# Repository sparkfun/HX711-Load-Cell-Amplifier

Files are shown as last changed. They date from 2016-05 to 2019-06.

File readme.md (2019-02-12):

HX711 Load Cell Amplifier
=======

Amplifier Layout

*[SparkFun Load Cell Amplifier - HX711](https://www.sparkfun.com/products/13230)*

The SparkFun Load Cell Amplifier is a small breakout board for the HX711 IC that allows you to easily read load cells to measure weight. By connecting the amplifier to your microcontroller you will be able to read the changes in the resistance of the load cell and with some calibration you’ll be able to get very accurate weight measurements. This can be handy for creating your own industrial scale, process control, or simple presence detection of an object.

The HX711 uses a two wire interface (Clock and Data) for communication. Any microcontroller’s GPIO pins should work and numerous libraries have been written making it easy to read data from the HX711.

Load cells use a four wire wheatstone bridge to connect to the HX711. These are commonly colored RED, BLK, WHT, GRN, and YLW. Each color corresponds to the conventional color coding of load cells:

* Red (Excitation+ or VCC)
* Black (Excitation- or GND)
* White (Amplifier+, Signal+, or Output+)
* Green (A-, S-, or O-)
* Yellow (Shield)

The YLW pin acts as an optional input that is not hooked up to the strain gauge but is utilized to ground and shield against outside EMI (electromagnetic interference). Please keep in mind that some load cells might have slight variations in color coding.

Repository Contents
-------------------

* **/Production_Files** - Panelized version of the design for production
* **/datasheets** - Datasheet for HX711 IC
* **/firmware** - Example Arduino sketches
* **/hardware** - All Eagle design files (.brd, .sch)

Documentation
--------------
* **[Library](https://github.com/bogde/HX711)** - Arduino library for the HX711
* **[Getting Started with Load Cells](https://learn.sparkfun.com/tutorials/getting-started-with-load-cells)** - Introduction to Load Cells
* **[Hookup Guide](https://learn.sparkfun.com/tutorials/load-cell-amplifier-hx711-breakout-hookup-guide)** - Basic hookup guide for the Load Cell Amplifier

License Information
-------------------

This design is [OSHW](http://www.oshwa.org/definition/) and public domain but you buy me a beer if you use this and we meet someday ([Beerware license](http://en.wikipedia.org/wiki/Beerware)).

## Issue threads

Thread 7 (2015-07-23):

Analog/Digital VDD

robwyatt, 2015-07-23:
I originally posted this to tech support, but they suggested I post here too.

If you guys respin this breakout board could you separate analog and digital supplies. The hx711 has separate digital and analog supplies but your board ties them together so its a pain to use with 3.3v micro and 5v strain gauge. If you bring the digital supply to the header people can externally tie them together if they want 5v digital.

The digital pins have to be the same voltage as the DVDD pin so running on 5v wasn't ideal, level shifting it possible but not ideal, running the whole thing on 3.3v kind of works but with less voltage on the strain gauge its a lot more susceptible to errors.

Ultimately I cut the track to pin 16 (DVDD) to isolate digital supply pin and soldered a wire to it for 3.3v - works like a charm but its messy.
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

ToniCorinne, 2015-07-27:
Thank you for the feedback! We'll keep this feedback in mind if/when this product comes up for review.

jmaerki, 2016-01-01:
A jumper for easy switching RATE between GND and DVDD would also be nice for experiments.

nseidle, 2016-01-21:
@jmaerki - Thanks for the feedback. Do check the schematic and the back of the PCB. There is a jumper that allows you connect RATE to GND or VCC.

AlexeiUOA, 2016-02-16:
Hi robwyatt,
I have the same goal, to increase the voltage on the load cell excitation to 5V.
The data sheet for the HX711 states that when using internal analog supply regulator, "The output voltage is equal to VAVDD=VBG*(R1+T2)/R1" where VBG is the "Reference bypass output"
Using the resistor values from the break out board, I get 1.25*(20+8.2)/20=1.76V.
So will changing the supply voltage 3V to 5V effect the excitation voltage, without the need to change the resisters? Or is there something I am missing?
Thanks in advanced!

AlexeiUOA, 2016-02-17:
Hi robwyatt,
Some interesting reading regarding ADC's and why the AVGND and DVGND are tied. Basically treat ADC's as analog devices, even though internally they are mixed systems. Tying the grounds reduces the noise that gets coupled from the digital side to the analog side from stray/parasitic capacitance.
The article condemns connecting DVGND to your projects digital ground plane, as this will cause a noisy ground plane for the ADC! Consistently the interference from this may be greater then the 2X gain in sensitivity that is acquired by switching form a 3V to 5V excitation voltage for the strain bridge
[staying_well_grounded Analog Devices Grounding Guide.pdf](https://github.com/sparkfun/HX711-Load-Cell-Amplifier/files/133583/staying_well_grounded.Analog.Devices.Grounding.Guide.pdf)
.

nseidle, 2016-02-18:
Hmm. Good points. We could provide a jumper to isolate the GNDs as well.

AlexeiUOA, 2016-02-18:
Hi nseidle,
Could you please clarify how the excitation voltage is calculated?
Because from the data sheet of HX711, then there will be a constant 1.76V at the excitation, independent of the input voltage using VAVDD=VBG(R1+T2)/R1 (so long as the supply voltage is between 2.6V and 5.5V).
And if I was to modify the breakout board circuit by replacing R2 with a 52K resister, what type of resister would I need? ie foot print on the PCB.
Do you know what type of resisters technology is used for R1 and R2 currently? eg Metal oxide, thin film, Bulk metal foil? (Just thinking of the temperature coefficient)
Many thanks

tk5ep, 2016-03-16:
Hi all,
I came to this post, looking for some infos about the HX711.
I noticed some strange things...

On both boards i have (not the Sparkfun but similar), i measured 1.287 V on the VBG pin.
The R1 and R2 resistors are respectively 20k and 8.2k

So the given formula gives : 1.287V *(28200)/20000 = 1.81V

BUT on the cell i measured the VAVDD and found 4.10 V on both boards.

I tried reversing R1 and R2, the formula gives : 1.287V *( 28200 ) /8200 = 4.42 V
So, something is wrong somewhere !

Who else did measure the VAVDD voltage ?? What are the values ?

Another point, regarding the AVDD and DVDD voltages. The datasheet says that the common mode input is max AVDD-1.3.
Can someone tell me (us) what that means ?

Many thanks,
Patrick.

ba05, 2020-11-27:
Old post but the old data sheet I believe had a wrong formula for calculating the excitation. Correct is AVDD = VBG(R1+R2)/R2

See here https://cdn.sparkfun.com/assets/f/5/5/b/c/SparkFun_HX711_Load_Cell.pdf

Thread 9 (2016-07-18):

HX711 Standalone

Priya003, 2016-07-18:
Hi, wanted to use HX711 24-bit adc standalone to measure voltage range of 2mv - 20mv.
Problem is:
1) I cannot interpret the adc output count.
2) What should i do in my code(code below) so that it prints voltages not decimal values.
Tried with different values of voltages(shared below), and i am totally confused with the readings. I don't know how to convert these values in voltage. What is the logic behind. Please help!
Readings:
0mv --- 5219
1.1mv --- 5095
2.3mv --- 4981
2.5mv --- 4960
2.9mv --- 4918
5mv --- 4693
10.6mv --- 4075
15.1mv --- 3597
22.7mv --- 2700
40.7mv --- 562
5volts --- -8388608
-5volts --- -8388607
Board is arduino leonardo, and a simple voltage divider is used for voltage generation(for testing only). The voltages are measured and calculated from multimeter and hand calculations. I need HX711 do this for me. What is the differential ADC count and voltage relationship...?
A bogde/HX711 library is used: https://github.com/bogde/HX711
Code:
`#include "HX711.h"
#define DOUT 3
#define CLK 2
HX711 scale(DOUT, CLK);
void setup() {
Serial.begin(115200);
}
void loop() {
long avg = scale.get_value(60);
Serial.print("Digital Code = ");
Serial.println(avg);
}`
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

BrentWilkins, 2016-07-18:
[Here](https://learn.sparkfun.com/tutorials/load-cell-amplifier-hx711-breakout-hookup-guide) is our documentation on our HX711 Breakout. We don't necessarily support 3rd party code. If you have more questions, please try asking in our [forums]9https://forum.sparkfun.com/) or our tech support team.

robwyatt, 2016-07-18:
I would suggest the hx711 is not the correct part for what you are trying to do. At best case you are way out of spec because its going to expect A+ and A- to be very close and somewhere near the half way point of E+ and E-, its not going to expect one of them to be grounded even if the voltage between them is only 20mv. More complex load cell systems would go in to error more if you did this because they sense it as a short circuit. The Sparkfun board also uses the built in voltage regulator so E+ is not simply VCC, E+ is being driven by the PNP transistor, via the base and feedback pins on the hx711 and I haven't really looked at what that pin does and I can't even speculate what it does if you ground one of the inputs.

If you have a single ended input I would suggest one of the many ADCs out there that will measure 20mv, at worst case use an op amp to condition the input.

If you want to use this in an esoteric way then you really have to start with a resistor bridge, get valid readings and then manipulate the bridge and resistor values until you get something you can use and that makes sense.

Closed 2016-07-18.

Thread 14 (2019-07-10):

Calibration

GoncaloFelicio, 2019-07-10:
Hi!
I would like to know more about calibration. Is specific, does the setup influence the calibration factor, or is the calibration factor a number i get from the calibration sketch and then i always use that same calibration factor?

In my case, i want to setup 4 loadcells to the same wood board, but can i calibrate before i screw them to the board, or can i only calibrate after i have my setup?

Thanks!

santaimpersonator, 2019-07-12:
Hi there, it sounds like you are looking for [technical assistance](https://www.sparkfun.com/technical_assistance). Unfortunately, this is not the place to get technical support; it is for filing problems with the code, library, or hardware. Use the link (above), to get started with posting a topic in our [forums](https://forum.sparkfun.com/). Our technical support team will do their best to assist you.

That being said, please check out the guides associated with this product:

- [Load Cell Amplifier HX711 Breakout Hookup Guide](https://learn.sparkfun.com/tutorials/load-cell-amplifier-hx711-breakout-hookup-guide)
- [Getting Started with Load Cells](https://learn.sparkfun.com/tutorials/getting-started-with-load-cells)

Closed 2019-07-12.

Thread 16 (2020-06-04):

RATE pin tied to VCC instead of VDD

santaimpersonator, 2020-06-04:
Brought up by customer: https://www.sparkfun.com/products/13879#comment-5ed8c67e423fad306c45dec4

`RATE` pin is a digital input an should be tied to VDD.

santaimpersonator, 2020-10-08:
From issue #7: https://github.com/sparkfun/HX711-Load-Cell-Amplifier/issues/7#issuecomment-168311195

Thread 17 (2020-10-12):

Feature Request: Filter on Channel B

santaimpersonator, 2020-10-12:
One of our customers suggested that including the filter, currently, on channel A to channel B as well... would be useful for customers.

farzadVaziriRaieni, 2023-06-12:
Does anyone know the part number of the L1 component? Is it actually a coil or a ferrite bead?

santaimpersonator, 2023-06-12:
@farzadVaziriRaieni For tracking purposes and best practice... please, create a new issue and avoid commenting a question on an unrelated post. (I am hiding you comment for now, but I will delete it by the end of the day as it is unrelated to this issue.)

With that said...

- You can refer to the SparkFun Eagle library for that component:
  https://github.com/sparkfun/SparkFun-Eagle-Libraries/blob/main/SparkFun-Coils.lbr#L1607
- You can also refer to the image of the product as well:
  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

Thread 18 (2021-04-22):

Connecting to LabVIEW (Cant find i2c slave address)

YudiNz, 2021-04-22:
hi there, I am trying to hook this up to a LabVIEW myRio student board and am running into problems.

I can design it such that I do not need a slave address to communicate but currently am trying to find out what the HX711 boards slave address is. Could someone help direct me to where I can find it. Currently the information below is what I know about it:

Information sent is between 800000h (MIN) or 7FFFFFh (MAX) which translates to 24bits in binary or 3 bytes of data
Pulse clock 25 times to read data that has a adc gain of 128 or 27 Pulses for a gain of 64.

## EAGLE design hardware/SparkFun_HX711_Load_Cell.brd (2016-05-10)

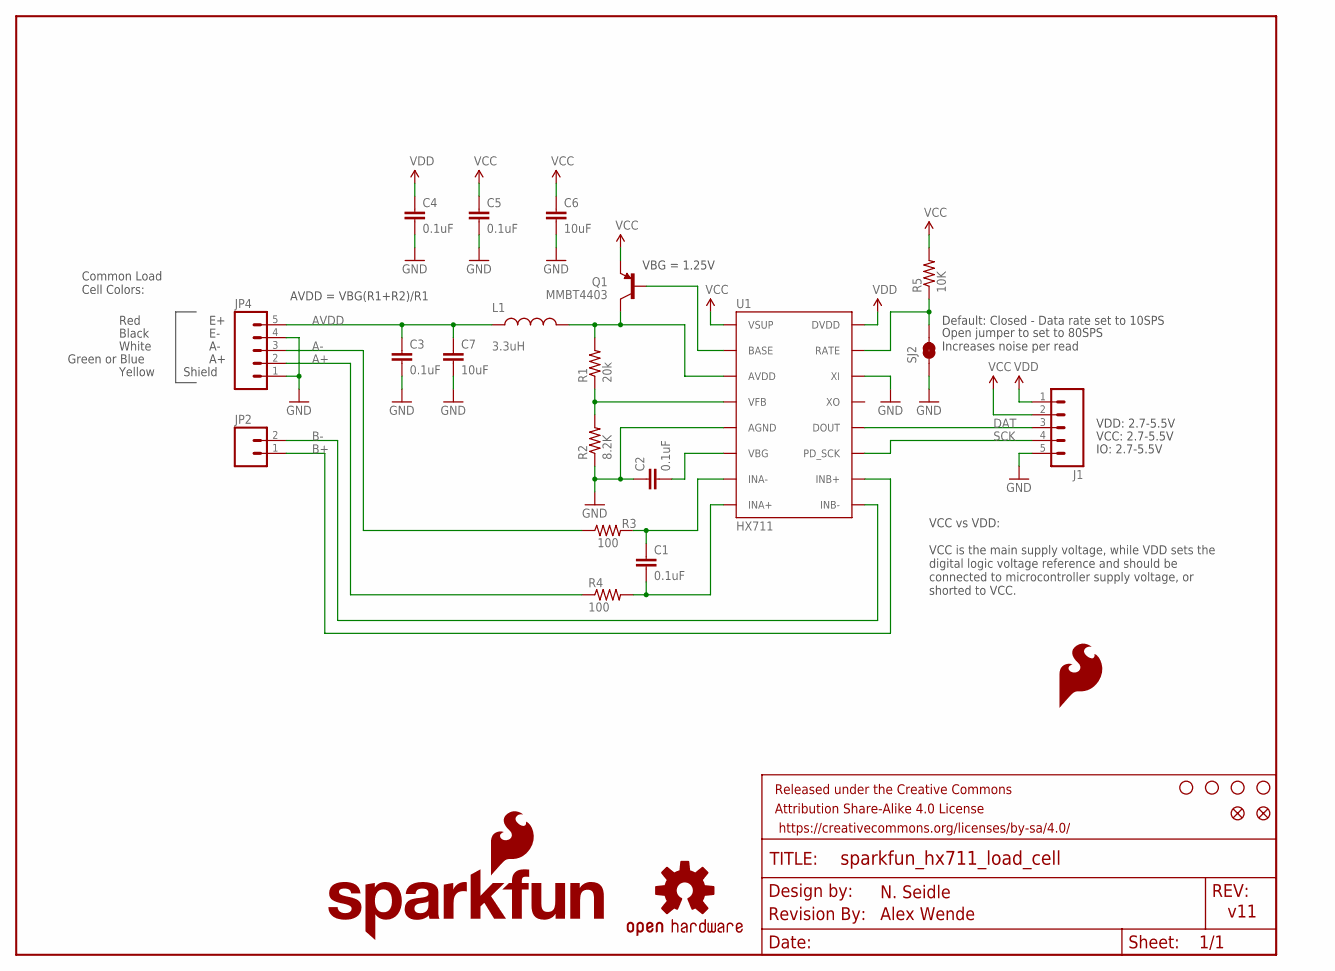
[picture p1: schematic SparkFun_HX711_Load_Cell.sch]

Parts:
C1, C2, C3, C4, C5: 0.1uF; 0603-CAP
C6, C7: 10uF; 1210
FID1, FID2: FIDUCIAL1X2; FIDUCIAL-1X2
FRAME1: FRAME-LETTER; CREATIVE_COMMONS
J1: M05PTH; 1X05
JP2: M02PTH; 1X02
JP4: M05PTH; 1X05
L1: 3.3uH; 0805
LOGO1: SFE_LOGO_NAME_FLAME.1_INCH; SFE_LOGO_NAME_FLAME_.1
LOGO3: SFE_LOGO_FLAME.1_INCH; SFE_LOGO_FLAME_.1
Q1: MMBT4403; SOT23-3
R1: 20k; 0603-RES
R2: 8.2K; 0603-RES
R3, R4: 100; 0603-RES
R5: 10K; 0603-RES
SJ2: JUMPER-PAD-2-NC_BY_TRACE; PAD-JUMPER-2-NC_BY_TRACE_YES_SILK
STANDOFF1, STANDOFF2, STANDOFF3, STANDOFF4: STAND-OFF
U1: HX711; SO16
U7: OSHW-LOGOS; OSHW-LOGO-S
U$1: REVISION

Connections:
A+: JP4.2, R4.1
A-: JP4.3, R3.1
AVDD: C3.1, C7.1, JP4.5, L1.1
B+: JP2.1, U1.10 (INB+)
B-: JP2.2, U1.9 (INB-)
DAT: J1.3, U1.12 (DOUT)
GND: C2.1, C3.2, C4.2, C5.2, C6.2, C7.2, J1.5, JP4.1, JP4.4, R2.1, SJ2.1, U1.5 (AGND), U1.14 (XI)
unnamed: R5.1, SJ2.2, U1.15 (RATE)
unnamed: C1.1, R3.2, U1.7 (INA-)
unnamed: C1.2, R4.2, U1.8 (INA+)
unnamed: Q1.1 (B), U1.2 (BASE)
unnamed: L1.2, Q1.3 (C), R1.2, U1.3 (AVDD)
unnamed: R1.1, R2.2, U1.4 (VFB)
unnamed: C2.2, U1.6 (VBG)
SCK: J1.4, U1.11 (PD_SCK)
VCC: C5.1, C6.1, J1.2, Q1.2 (E), R5.2, U1.1 (VSUP)
VDD: C4.1, J1.1, U1.16 (DVDD)

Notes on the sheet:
VCC: 2.7-5.5V
VBG = 1.25V
AVDD = VBG(R1+R2)/R1
Default: Closed - Data rate set to 10SPS
Open jumper to set to 80SPS Increases noise per read
Red
Black
White
Green or Blue
Common Load Cell Colors:
IO: 2.7-5.5V
Shield
Yellow
VDD: 2.7-5.5V
VCC vs VDD: VCC is the main supply voltage, while VDD sets the digital logic voltage reference and should be connected to microcontroller supply voltage, or shorted to VCC.
Alex Wende
N. Seidle
v11

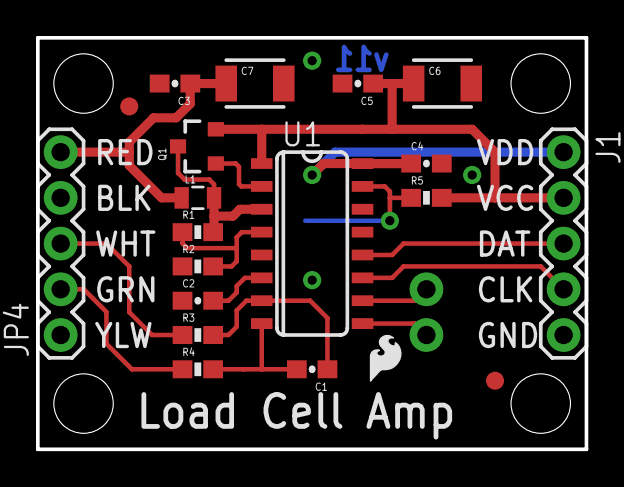
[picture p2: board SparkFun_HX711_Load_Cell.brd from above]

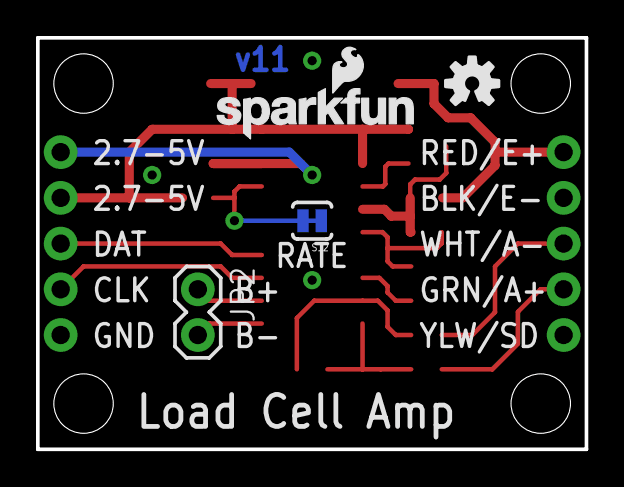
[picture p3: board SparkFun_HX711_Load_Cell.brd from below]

Board: 2 copper layers, 30.5 x 22.9 mm, 30 parts (4 on the bottom side), 17 nets.

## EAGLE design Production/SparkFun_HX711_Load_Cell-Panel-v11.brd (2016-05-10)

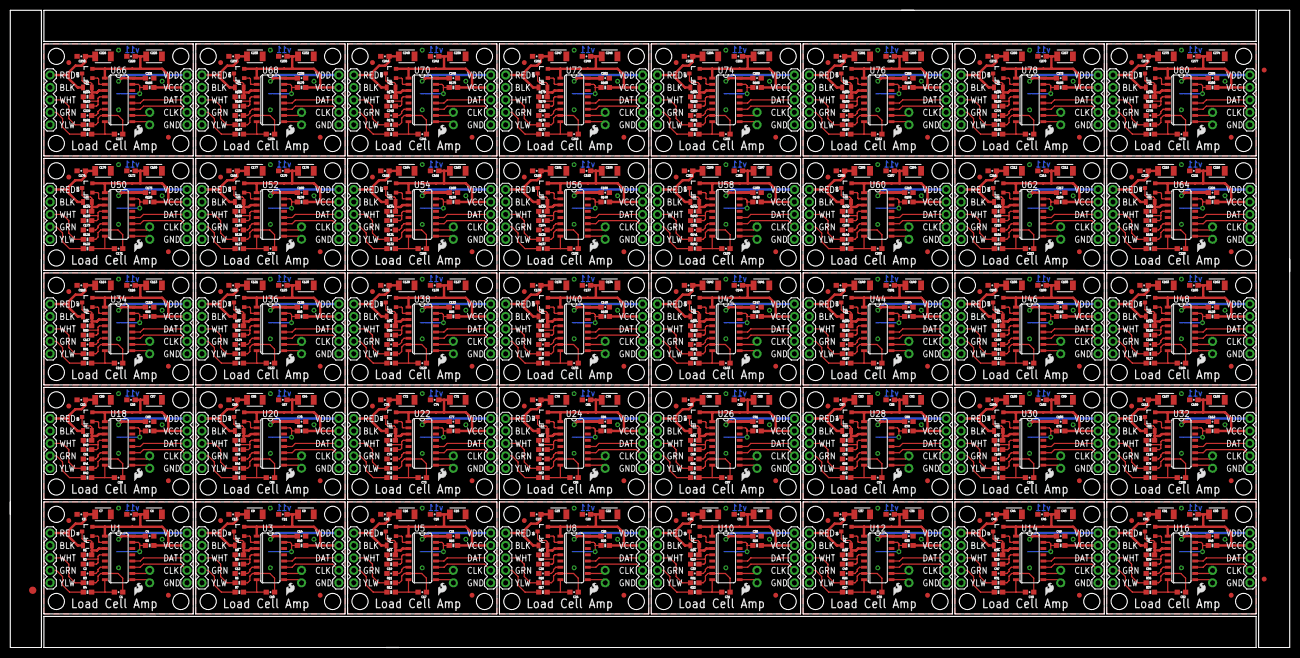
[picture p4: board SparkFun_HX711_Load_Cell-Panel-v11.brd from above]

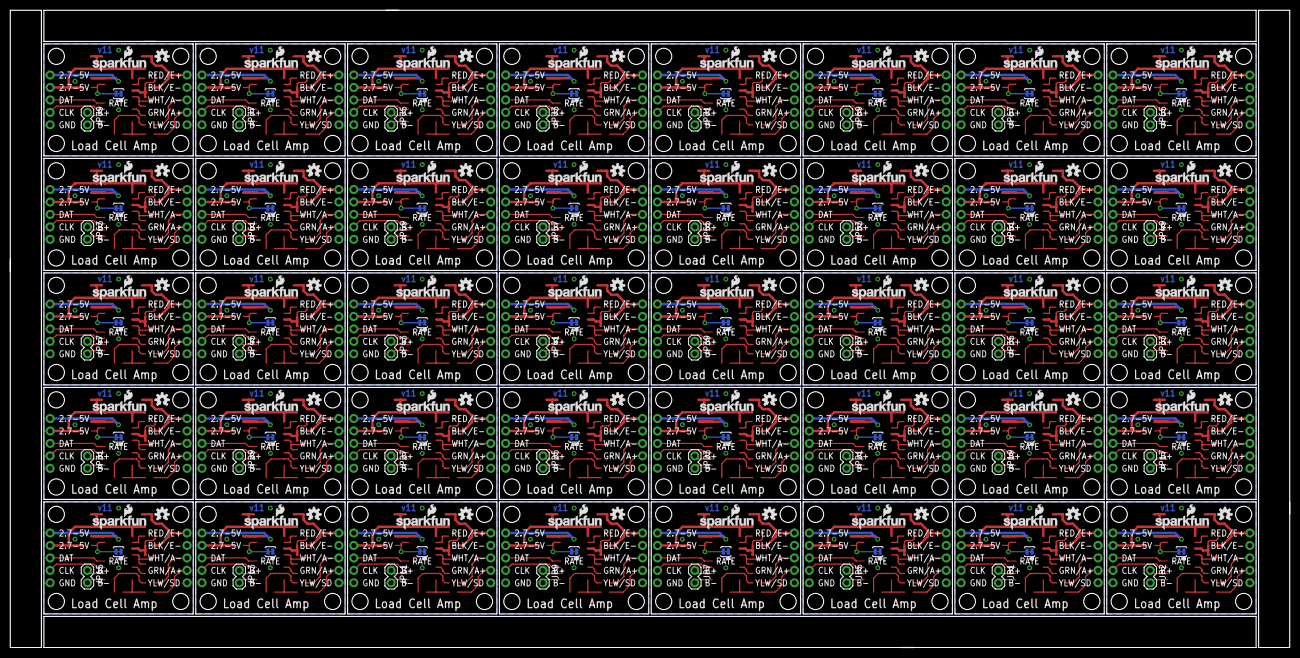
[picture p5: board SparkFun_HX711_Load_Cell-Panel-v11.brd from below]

Board: 2 copper layers, 261.1 x 130.0 mm, 1123 parts (160 on the bottom side), 680 nets.

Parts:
C1, C2, C3, C4, C5, C10, C11, C12, C13, C14, C17, C18, C19, C20, C21, C24, C25, C26, C27, C28, C31, C32, C33, C34, C35, C38, C39, C40, C41, C42, C45, C46, C47, C48, C49, C52, C53, C54, C55, C56, C59, C60, C61, C62, C63, C66, C67, C68, C69, C70, C73, C74, C75, C76, C77, C80, C81, C82, C83, C84, C87, C88, C89, C90, C91, C94, C95, C96, C97, C98, C101, C102, C103, C104, C105, C108, C109, C110, C111, C112, C115, C116, C117, C118, C119, C122, C123, C124, C125, C126, C129, C130, C131, C132, C133, C136, C137, C138, C139, C140, C143, C144, C145, C146, C147, C150, C151, C152, C153, C154, C157, C158, C159, C160, C161, C164, C165, C166, C167, C168, C171, C172, C173, C174, C175, C178, C179, C180, C181, C182, C185, C186, C187, C188, C189, C192, C193, C194, C195, C196, C199, C200, C201, C202, C203, C206, C207, C208, C209, C210, C213, C214, C215, C216, C217, C220, C221, C222, C223, C224, C227, C228, C229, C230, C231, C234, C235, C236, C237, C238, C241, C242, C243, C244, C245, C248, C249, C250, C251, C252, C255, C256, C257, C258, C259, C262, C263, C264, C265, C266, C269, C270, C271, C272, C273, C276, C277, C278, C279, C280: 0.1uF; 0603-CAP
C6, C7, C8, C9, C15, C16, C22, C23, C29, C30, C36, C37, C43, C44, C50, C51, C57, C58, C64, C65, C71, C72, C78, C79, C85, C86, C92, C93, C99, C100, C106, C107, C113, C114, C120, C121, C127, C128, C134, C135, C141, C142, C148, C149, C155, C156, C162, C163, C169, C170, C176, C177, C183, C184, C190, C191, C197, C198, C204, C205, C211, C212, C218, C219, C225, C226, C232, C233, C239, C240, C246, C247, C253, C254, C260, C261, C267, C268, C274, C275: 10uF; 1210
E$1: FIDUCIAL-1.5X3
E$5, E$6: FIDUCIAL-1X2
FID1, FID2, FID3, FID4, FID5, FID6, FID7, FID8, FID9, FID10, FID11, FID12, FID13, FID14, FID15, FID16, FID17, FID18, FID19, FID20, FID21, FID22, FID23, FID24, FID25, FID26, FID27, FID28, FID29, FID30, FID31, FID32, FID33, FID34, FID35, FID36, FID37, FID38, FID39, FID40, FID41, FID42, FID43, FID44, FID45, FID46, FID47, FID48, FID49, FID50, FID51, FID52, FID53, FID54, FID55, FID56, FID57, FID58, FID59, FID60, FID61, FID62, FID63, FID64, FID65, FID66, FID67, FID68, FID69, FID70, FID71, FID72, FID73, FID74, FID75, FID76, FID77, FID78, FID79, FID80: FIDUCIAL1X2; FIDUCIAL-1X2
J1, J2, J3, J4, J5, J6, J7, J8, J9, J10, J11, J12, J13, J14, J15, J16, J17, J18, J19, J20, J21, J22, J23, J24, J25, J26, J27, J28, J29, J30, J31, J32, J33, J34, J35, J36, J37, J38, J39, J40: 1X05
JP1, JP2, JP5, JP7, JP9, JP11, JP13, JP15, JP17, JP19, JP21, JP23, JP25, JP27, JP29, JP31, JP33, JP35, JP37, JP39, JP41, JP43, JP45, JP47, JP49, JP51, JP53, JP55, JP57, JP59, JP61, JP63, JP65, JP67, JP69, JP71, JP73, JP75, JP77, JP79: 1X02
JP3, JP4, JP6, JP8, JP10, JP12, JP14, JP16, JP18, JP20, JP22, JP24, JP26, JP28, JP30, JP32, JP34, JP36, JP38, JP40, JP42, JP44, JP46, JP48, JP50, JP52, JP54, JP56, JP58, JP60, JP62, JP64, JP66, JP68, JP70, JP72, JP74, JP76, JP78, JP80: 1X05
L1, L2, L3, L4, L5, L6, L7, L8, L9, L10, L11, L12, L13, L14, L15, L16, L17, L18, L19, L20, L21, L22, L23, L24, L25, L26, L27, L28, L29, L30, L31, L32, L33, L34, L35, L36, L37, L38, L39, L40: 3.3uH; 0805
LOGO1, LOGO2, LOGO5, LOGO7, LOGO9, LOGO11, LOGO13, LOGO15, LOGO17, LOGO19, LOGO21, LOGO23, LOGO25, LOGO27, LOGO29, LOGO31, LOGO33, LOGO35, LOGO37, LOGO39, LOGO41, LOGO43, LOGO45, LOGO47, LOGO49, LOGO51, LOGO53, LOGO55, LOGO57, LOGO59, LOGO61, LOGO63, LOGO65, LOGO67, LOGO69, LOGO71, LOGO73, LOGO75, LOGO77, LOGO79: SFE_LOGO_NAME_FLAME.1_INCH; SFE_LOGO_NAME_FLAME_.1
LOGO3, LOGO4, LOGO6, LOGO8, LOGO10, LOGO12, LOGO14, LOGO16, LOGO18, LOGO20, LOGO22, LOGO24, LOGO26, LOGO28, LOGO30, LOGO32, LOGO34, LOGO36, LOGO38, LOGO40, LOGO42, LOGO44, LOGO46, LOGO48, LOGO50, LOGO52, LOGO54, LOGO56, LOGO58, LOGO60, LOGO62, LOGO64, LOGO66, LOGO68, LOGO70, LOGO72, LOGO74, LOGO76, LOGO78, LOGO80: SFE_LOGO_FLAME.1_INCH; SFE_LOGO_FLAME_.1
Q1, Q2, Q3, Q4, Q5, Q6, Q7, Q8, Q9, Q10, Q11, Q12, Q13, Q14, Q15, Q16, Q17, Q18, Q19, Q20, Q21, Q22, Q23, Q24, Q25, Q26, Q27, Q28, Q29, Q30, Q31, Q32, Q33, Q34, Q35, Q36, Q37, Q38, Q39, Q40: MMBT4403; SOT23-3
R1, R9, R14, R19, R24, R29, R34, R39, R44, R49, R54, R59, R64, R69, R74, R79, R84, R89, R94, R99, R104, R109, R114, R119, R124, R129, R134, R139, R144, R149, R154, R159, R164, R169, R174, R179, R184, R189, R194, R199: 20k; 0603-RES
R2, R8, R13, R18, R23, R28, R33, R38, R43, R48, R53, R58, R63, R68, R73, R78, R83, R88, R93, R98, R103, R108, R113, R118, R123, R128, R133, R138, R143, R148, R153, R158, R163, R168, R173, R178, R183, R188, R193, R198: 8.2K; 0603-RES
R3, R4, R6, R7, R11, R12, R16, R17, R21, R22, R26, R27, R31, R32, R36, R37, R41, R42, R46, R47, R51, R52, R56, R57, R61, R62, R66, R67, R71, R72, R76, R77, R81, R82, R86, R87, R91, R92, R96, R97, R101, R102, R106, R107, R111, R112, R116, R117, R121, R122, R126, R127, R131, R132, R136, R137, R141, R142, R146, R147, R151, R152, R156, R157, R161, R162, R166, R167, R171, R172, R176, R177, R181, R182, R186, R187, R191, R192, R196, R197: 100; 0603-RES
R5, R10, R15, R20, R25, R30, R35, R40, R45, R50, R55, R60, R65, R70, R75, R80, R85, R90, R95, R100, R105, R110, R115, R120, R125, R130, R135, R140, R145, R150, R155, R160, R165, R170, R175, R180, R185, R190, R195, R200: 10K; 0603-RES
SJ1, SJ2, SJ3, SJ4, SJ5, SJ6, SJ7, SJ8, SJ9, SJ10, SJ11, SJ12, SJ13, SJ14, SJ15, SJ16, SJ17, SJ18, SJ19, SJ20, SJ21, SJ22, SJ23, SJ24, SJ25, SJ26, SJ27, SJ28, SJ29, SJ30, SJ31, SJ32, SJ33, SJ34, SJ35, SJ36, SJ37, SJ38, SJ39, SJ40: PAD-JUMPER-2-NC_BY_TRACE_YES_SILK
STANDOFF1, STANDOFF2, STANDOFF3, STANDOFF4, STANDOFF5, STANDOFF6, STANDOFF7, STANDOFF8, STANDOFF9, STANDOFF10, STANDOFF11, STANDOFF12, STANDOFF13, STANDOFF14, STANDOFF15, STANDOFF16, STANDOFF17, STANDOFF18, STANDOFF19, STANDOFF20, STANDOFF21, STANDOFF22, STANDOFF23, STANDOFF24, STANDOFF25, STANDOFF26, STANDOFF27, STANDOFF28, STANDOFF29, STANDOFF30, STANDOFF31, STANDOFF32, STANDOFF33, STANDOFF34, STANDOFF35, STANDOFF36, STANDOFF37, STANDOFF38, STANDOFF39, STANDOFF40, STANDOFF41, STANDOFF42, STANDOFF43, STANDOFF44, STANDOFF45, STANDOFF46, STANDOFF47, STANDOFF48, STANDOFF49, STANDOFF50, STANDOFF51, STANDOFF52, STANDOFF53, STANDOFF54, STANDOFF55, STANDOFF56, STANDOFF57, STANDOFF58, STANDOFF59, STANDOFF60, STANDOFF61, STANDOFF62, STANDOFF63, STANDOFF64, STANDOFF65, STANDOFF66, STANDOFF67, STANDOFF68, STANDOFF69, STANDOFF70, STANDOFF71, STANDOFF72, STANDOFF73, STANDOFF74, STANDOFF75, STANDOFF76, STANDOFF77, STANDOFF78, STANDOFF79, STANDOFF80, STANDOFF81, STANDOFF82, STANDOFF83, STANDOFF84, STANDOFF85, STANDOFF86, STANDOFF87, STANDOFF88, STANDOFF89, STANDOFF90, STANDOFF91, STANDOFF92, STANDOFF93, STANDOFF94, STANDOFF95, STANDOFF96, STANDOFF97, STANDOFF98, STANDOFF99, STANDOFF100, STANDOFF101, STANDOFF102, STANDOFF103, STANDOFF104, STANDOFF105, STANDOFF106, STANDOFF107, STANDOFF108, STANDOFF109, STANDOFF110, STANDOFF111, STANDOFF112, STANDOFF113, STANDOFF114, STANDOFF115, STANDOFF116, STANDOFF117, STANDOFF118, STANDOFF119, STANDOFF120, STANDOFF121, STANDOFF122, STANDOFF123, STANDOFF124, STANDOFF125, STANDOFF126, STANDOFF127, STANDOFF128, STANDOFF129, STANDOFF130, STANDOFF131, STANDOFF132, STANDOFF133, STANDOFF134, STANDOFF135, STANDOFF136, STANDOFF137, STANDOFF138, STANDOFF139, STANDOFF140, STANDOFF141, STANDOFF142, STANDOFF143, STANDOFF144, STANDOFF145, STANDOFF146, STANDOFF147, STANDOFF148, STANDOFF149, STANDOFF150, STANDOFF151, STANDOFF152, STANDOFF153, STANDOFF154, STANDOFF155, STANDOFF156, STANDOFF157, STANDOFF158, STANDOFF159, STANDOFF160: STAND-OFF
U1, U3, U5, U8, U10, U12, U14, U16, U18, U20, U22, U24, U26, U28, U30, U32, U34, U36, U38, U40, U42, U44, U46, U48, U50, U52, U54, U56, U58, U60, U62, U64, U66, U68, U70, U72, U74, U76, U78, U80: HX711; SO16
U2, U4, U6, U7, U9, U11, U13, U15, U17, U19, U21, U23, U25, U27, U29, U31, U33, U35, U37, U39, U41, U43, U45, U47, U49, U51, U53, U55, U57, U59, U61, U63, U65, U67, U69, U71, U73, U75, U77, U79: OSHW-LOGOS; OSHW-LOGO-S

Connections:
A+: JP4.2, R4.1
A+1: JP3.2, R7.1
A+2: JP6.2, R12.1
A+3: JP8.2, R17.1
A+4: JP10.2, R22.1
A+5: JP12.2, R27.1
A+6: JP14.2, R32.1
A+7: JP16.2, R37.1
A+8: JP18.2, R42.1
A+9: JP20.2, R47.1
A+10: JP22.2, R52.1
A+11: JP24.2, R57.1
A+12: JP26.2, R62.1
A+13: JP28.2, R67.1
A+14: JP30.2, R72.1
A+15: JP32.2, R77.1
A+16: JP34.2, R82.1
A+17: JP36.2, R87.1
A+18: JP38.2, R92.1
A+19: JP40.2, R97.1
A+20: JP42.2, R102.1
A+21: JP44.2, R107.1
A+22: JP46.2, R112.1
A+23: JP48.2, R117.1
A+24: JP50.2, R122.1
A+25: JP52.2, R127.1
A+26: JP54.2, R132.1
A+27: JP56.2, R137.1
A+28: JP58.2, R142.1
A+29: JP60.2, R147.1
A+30: JP62.2, R152.1
A+31: JP64.2, R157.1
A+32: JP66.2, R162.1
A+33: JP68.2, R167.1
A+34: JP70.2, R172.1
A+35: JP72.2, R177.1
A+36: JP74.2, R182.1
A+37: JP76.2, R187.1
A+38: JP78.2, R192.1
A+39: JP80.2, R197.1
A-: JP4.3, R3.1
A-1: JP3.3, R6.1
A-2: JP6.3, R11.1
A-3: JP8.3, R16.1
A-4: JP10.3, R21.1
A-5: JP12.3, R26.1
A-6: JP14.3, R31.1
A-7: JP16.3, R36.1
A-8: JP18.3, R41.1
A-9: JP20.3, R46.1
A-10: JP22.3, R51.1
A-11: JP24.3, R56.1
A-12: JP26.3, R61.1
A-13: JP28.3, R66.1
A-14: JP30.3, R71.1
A-15: JP32.3, R76.1
A-16: JP34.3, R81.1
A-17: JP36.3, R86.1
A-18: JP38.3, R91.1
A-19: JP40.3, R96.1
A-20: JP42.3, R101.1
A-21: JP44.3, R106.1
A-22: JP46.3, R111.1
A-23: JP48.3, R116.1
A-24: JP50.3, R121.1
A-25: JP52.3, R126.1
A-26: JP54.3, R131.1
A-27: JP56.3, R136.1
A-28: JP58.3, R141.1
A-29: JP60.3, R146.1
A-30: JP62.3, R151.1
A-31: JP64.3, R156.1
A-32: JP66.3, R161.1
A-33: JP68.3, R166.1
A-34: JP70.3, R171.1
A-35: JP72.3, R176.1
A-36: JP74.3, R181.1
A-37: JP76.3, R186.1
A-38: JP78.3, R191.1
A-39: JP80.3, R196.1
AVDD: C3.1, C7.1, JP4.5, L1.1
AVDD1: C9.1, C13.1, JP3.5, L2.1
AVDD2: C16.1, C20.1, JP6.5, L3.1
AVDD3: C23.1, C27.1, JP8.5, L4.1
AVDD4: C30.1, C34.1, JP10.5, L5.1
AVDD5: C37.1, C41.1, JP12.5, L6.1
AVDD6: C44.1, C48.1, JP14.5, L7.1
AVDD7: C51.1, C55.1, JP16.5, L8.1
AVDD8: C58.1, C62.1, JP18.5, L9.1
AVDD9: C65.1, C69.1, JP20.5, L10.1
AVDD10: C72.1, C76.1, JP22.5, L11.1
AVDD11: C79.1, C83.1, JP24.5, L12.1
AVDD12: C86.1, C90.1, JP26.5, L13.1
AVDD13: C93.1, C97.1, JP28.5, L14.1
AVDD14: C100.1, C104.1, JP30.5, L15.1
AVDD15: C107.1, C111.1, JP32.5, L16.1
AVDD16: C114.1, C118.1, JP34.5, L17.1
AVDD17: C121.1, C125.1, JP36.5, L18.1
AVDD18: C128.1, C132.1, JP38.5, L19.1
AVDD19: C135.1, C139.1, JP40.5, L20.1
AVDD20: C142.1, C146.1, JP42.5, L21.1
AVDD21: C149.1, C153.1, JP44.5, L22.1
AVDD22: C156.1, C160.1, JP46.5, L23.1
AVDD23: C163.1, C167.1, JP48.5, L24.1
AVDD24: C170.1, C174.1, JP50.5, L25.1
AVDD25: C177.1, C181.1, JP52.5, L26.1
AVDD26: C184.1, C188.1, JP54.5, L27.1
AVDD27: C191.1, C195.1, JP56.5, L28.1
AVDD28: C198.1, C202.1, JP58.5, L29.1
AVDD29: C205.1, C209.1, JP60.5, L30.1
AVDD30: C212.1, C216.1, JP62.5, L31.1
AVDD31: C219.1, C223.1, JP64.5, L32.1
AVDD32: C226.1, C230.1, JP66.5, L33.1
AVDD33: C233.1, C237.1, JP68.5, L34.1
AVDD34: C240.1, C244.1, JP70.5, L35.1
AVDD35: C247.1, C251.1, JP72.5, L36.1
AVDD36: C254.1, C258.1, JP74.5, L37.1
AVDD37: C261.1, C265.1, JP76.5, L38.1
AVDD38: C268.1, C272.1, JP78.5, L39.1
AVDD39: C275.1, C279.1, JP80.5, L40.1
B+: JP2.1, U1.10
B+1: JP1.1, U3.10
B+2: JP5.1, U5.10
B+3: JP7.1, U8.10
B+4: JP9.1, U10.10
B+5: JP11.1, U12.10
B+6: JP13.1, U14.10
B+7: JP15.1, U16.10
B+8: JP17.1, U18.10
B+9: JP19.1, U20.10
B+10: JP21.1, U22.10
B+11: JP23.1, U24.10
B+12: JP25.1, U26.10
B+13: JP27.1, U28.10
B+14: JP29.1, U30.10
B+15: JP31.1, U32.10
B+16: JP33.1, U34.10
B+17: JP35.1, U36.10
B+18: JP37.1, U38.10
B+19: JP39.1, U40.10
B+20: JP41.1, U42.10
B+21: JP43.1, U44.10
B+22: JP45.1, U46.10
B+23: JP47.1, U48.10
B+24: JP49.1, U50.10
B+25: JP51.1, U52.10
B+26: JP53.1, U54.10
B+27: JP55.1, U56.10
B+28: JP57.1, U58.10
B+29: JP59.1, U60.10
B+30: JP61.1, U62.10
B+31: JP63.1, U64.10
B+32: JP65.1, U66.10
B+33: JP67.1, U68.10
B+34: JP69.1, U70.10
B+35: JP71.1, U72.10
B+36: JP73.1, U74.10
B+37: JP75.1, U76.10
B+38: JP77.1, U78.10
B+39: JP79.1, U80.10
B-: JP2.2, U1.9
B-1: JP1.2, U3.9
B-2: JP5.2, U5.9
B-3: JP7.2, U8.9
B-4: JP9.2, U10.9
B-5: JP11.2, U12.9
B-6: JP13.2, U14.9
B-7: JP15.2, U16.9
B-8: JP17.2, U18.9
B-9: JP19.2, U20.9
B-10: JP21.2, U22.9
B-11: JP23.2, U24.9
B-12: JP25.2, U26.9
B-13: JP27.2, U28.9
B-14: JP29.2, U30.9
B-15: JP31.2, U32.9
B-16: JP33.2, U34.9
B-17: JP35.2, U36.9
B-18: JP37.2, U38.9
B-19: JP39.2, U40.9
B-20: JP41.2, U42.9
B-21: JP43.2, U44.9
B-22: JP45.2, U46.9
B-23: JP47.2, U48.9
B-24: JP49.2, U50.9
B-25: JP51.2, U52.9
B-26: JP53.2, U54.9
B-27: JP55.2, U56.9
B-28: JP57.2, U58.9
B-29: JP59.2, U60.9
B-30: JP61.2, U62.9
B-31: JP63.2, U64.9
B-32: JP65.2, U66.9
B-33: JP67.2, U68.9
B-34: JP69.2, U70.9
B-35: JP71.2, U72.9
B-36: JP73.2, U74.9
B-37: JP75.2, U76.9
B-38: JP77.2, U78.9
B-39: JP79.2, U80.9
DAT: J1.3, U1.12
DAT1: J2.3, U3.12
DAT2: J3.3, U5.12
DAT3: J4.3, U8.12
DAT4: J5.3, U10.12
DAT5: J6.3, U12.12
DAT6: J7.3, U14.12
DAT7: J8.3, U16.12
DAT8: J9.3, U18.12
DAT9: J10.3, U20.12
DAT10: J11.3, U22.12
DAT11: J12.3, U24.12
DAT12: J13.3, U26.12
DAT13: J14.3, U28.12
DAT14: J15.3, U30.12
DAT15: J16.3, U32.12
DAT16: J17.3, U34.12
DAT17: J18.3, U36.12
DAT18: J19.3, U38.12
DAT19: J20.3, U40.12
DAT20: J21.3, U42.12
DAT21: J22.3, U44.12
DAT22: J23.3, U46.12
DAT23: J24.3, U48.12
DAT24: J25.3, U50.12
DAT25: J26.3, U52.12
DAT26: J27.3, U54.12
DAT27: J28.3, U56.12
DAT28: J29.3, U58.12
DAT29: J30.3, U60.12
DAT30: J31.3, U62.12
DAT31: J32.3, U64.12
DAT32: J33.3, U66.12
DAT33: J34.3, U68.12
DAT34: J35.3, U70.12
DAT35: J36.3, U72.12
DAT36: J37.3, U74.12
DAT37: J38.3, U76.12
DAT38: J39.3, U78.12
DAT39: J40.3, U80.12
GND: C2.1, C3.2, C4.2, C5.2, C6.2, C7.2, J1.5, JP4.1, JP4.4, R2.1, SJ2.1, U1.5, U1.14
GND1: C8.2, C9.2, C11.2, C12.1, C13.2, C14.2, J2.5, JP3.1, JP3.4, R8.1, SJ1.1, U3.5, U3.14
GND2: C15.2, C16.2, C18.2, C19.1, C20.2, C21.2, J3.5, JP6.1, JP6.4, R13.1, SJ3.1, U5.5, U5.14
GND3: C22.2, C23.2, C25.2, C26.1, C27.2, C28.2, J4.5, JP8.1, JP8.4, R18.1, SJ4.1, U8.5, U8.14
GND4: C29.2, C30.2, C32.2, C33.1, C34.2, C35.2, J5.5, JP10.1, JP10.4, R23.1, SJ5.1, U10.5, U10.14
GND5: C36.2, C37.2, C39.2, C40.1, C41.2, C42.2, J6.5, JP12.1, JP12.4, R28.1, SJ6.1, U12.5, U12.14
GND6: C43.2, C44.2, C46.2, C47.1, C48.2, C49.2, J7.5, JP14.1, JP14.4, R33.1, SJ7.1, U14.5, U14.14
GND7: C50.2, C51.2, C53.2, C54.1, C55.2, C56.2, J8.5, JP16.1, JP16.4, R38.1, SJ8.1, U16.5, U16.14
GND8: C57.2, C58.2, C60.2, C61.1, C62.2, C63.2, J9.5, JP18.1, JP18.4, R43.1, SJ9.1, U18.5, U18.14
GND9: C64.2, C65.2, C67.2, C68.1, C69.2, C70.2, J10.5, JP20.1, JP20.4, R48.1, SJ10.1, U20.5, U20.14
GND10: C71.2, C72.2, C74.2, C75.1, C76.2, C77.2, J11.5, JP22.1, JP22.4, R53.1, SJ11.1, U22.5, U22.14
GND11: C78.2, C79.2, C81.2, C82.1, C83.2, C84.2, J12.5, JP24.1, JP24.4, R58.1, SJ12.1, U24.5, U24.14
GND12: C85.2, C86.2, C88.2, C89.1, C90.2, C91.2, J13.5, JP26.1, JP26.4, R63.1, SJ13.1, U26.5, U26.14
GND13: C92.2, C93.2, C95.2, C96.1, C97.2, C98.2, J14.5, JP28.1, JP28.4, R68.1, SJ14.1, U28.5, U28.14
GND14: C99.2, C100.2, C102.2, C103.1, C104.2, C105.2, J15.5, JP30.1, JP30.4, R73.1, SJ15.1, U30.5, U30.14
GND15: C106.2, C107.2, C109.2, C110.1, C111.2, C112.2, J16.5, JP32.1, JP32.4, R78.1, SJ16.1, U32.5, U32.14
GND16: C113.2, C114.2, C116.2, C117.1, C118.2, C119.2, J17.5, JP34.1, JP34.4, R83.1, SJ17.1, U34.5, U34.14
GND17: C120.2, C121.2, C123.2, C124.1, C125.2, C126.2, J18.5, JP36.1, JP36.4, R88.1, SJ18.1, U36.5, U36.14
GND18: C127.2, C128.2, C130.2, C131.1, C132.2, C133.2, J19.5, JP38.1, JP38.4, R93.1, SJ19.1, U38.5, U38.14
GND19: C134.2, C135.2, C137.2, C138.1, C139.2, C140.2, J20.5, JP40.1, JP40.4, R98.1, SJ20.1, U40.5, U40.14
GND20: C141.2, C142.2, C144.2, C145.1, C146.2, C147.2, J21.5, JP42.1, JP42.4, R103.1, SJ21.1, U42.5, U42.14
GND21: C148.2, C149.2, C151.2, C152.1, C153.2, C154.2, J22.5, JP44.1, JP44.4, R108.1, SJ22.1, U44.5, U44.14
GND22: C155.2, C156.2, C158.2, C159.1, C160.2, C161.2, J23.5, JP46.1, JP46.4, R113.1, SJ23.1, U46.5, U46.14
GND23: C162.2, C163.2, C165.2, C166.1, C167.2, C168.2, J24.5, JP48.1, JP48.4, R118.1, SJ24.1, U48.5, U48.14
GND24: C169.2, C170.2, C172.2, C173.1, C174.2, C175.2, J25.5, JP50.1, JP50.4, R123.1, SJ25.1, U50.5, U50.14
GND25: C176.2, C177.2, C179.2, C180.1, C181.2, C182.2, J26.5, JP52.1, JP52.4, R128.1, SJ26.1, U52.5, U52.14
GND26: C183.2, C184.2, C186.2, C187.1, C188.2, C189.2, J27.5, JP54.1, JP54.4, R133.1, SJ27.1, U54.5, U54.14
GND27: C190.2, C191.2, C193.2, C194.1, C195.2, C196.2, J28.5, JP56.1, JP56.4, R138.1, SJ28.1, U56.5, U56.14
GND28: C197.2, C198.2, C200.2, C201.1, C202.2, C203.2, J29.5, JP58.1, JP58.4, R143.1, SJ29.1, U58.5, U58.14
GND29: C204.2, C205.2, C207.2, C208.1, C209.2, C210.2, J30.5, JP60.1, JP60.4, R148.1, SJ30.1, U60.5, U60.14
GND30: C211.2, C212.2, C214.2, C215.1, C216.2, C217.2, J31.5, JP62.1, JP62.4, R153.1, SJ31.1, U62.5, U62.14
GND31: C218.2, C219.2, C221.2, C222.1, C223.2, C224.2, J32.5, JP64.1, JP64.4, R158.1, SJ32.1, U64.5, U64.14
GND32: C225.2, C226.2, C228.2, C229.1, C230.2, C231.2, J33.5, JP66.1, JP66.4, R163.1, SJ33.1, U66.5, U66.14
GND33: C232.2, C233.2, C235.2, C236.1, C237.2, C238.2, J34.5, JP68.1, JP68.4, R168.1, SJ34.1, U68.5, U68.14
GND34: C239.2, C240.2, C242.2, C243.1, C244.2, C245.2, J35.5, JP70.1, JP70.4, R173.1, SJ35.1, U70.5, U70.14
GND35: C246.2, C247.2, C249.2, C250.1, C251.2, C252.2, J36.5, JP72.1, JP72.4, R178.1, SJ36.1, U72.5, U72.14
GND36: C253.2, C254.2, C256.2, C257.1, C258.2, C259.2, J37.5, JP74.1, JP74.4, R183.1, SJ37.1, U74.5, U74.14
GND37: C260.2, C261.2, C263.2, C264.1, C265.2, C266.2, J38.5, JP76.1, JP76.4, R188.1, SJ38.1, U76.5, U76.14
GND38: C267.2, C268.2, C270.2, C271.1, C272.2, C273.2, J39.5, JP78.1, JP78.4, R193.1, SJ39.1, U78.5, U78.14
GND39: C274.2, C275.2, C277.2, C278.1, C279.2, C280.2, J40.5, JP80.1, JP80.4, R198.1, SJ40.1, U80.5, U80.14
unnamed: R5.1, SJ2.2, U1.15
unnamed: C1.1, R3.2, U1.7
unnamed: C1.2, R4.2, U1.8
unnamed: Q1.1, U1.2
unnamed: L1.2, Q1.3, R1.2, U1.3
unnamed: R1.1, R2.2, U1.4
unnamed: C2.2, U1.6
unnamed: Q2.1, U3.2
unnamed: R8.2, R9.1, U3.4
unnamed: C12.2, U3.6
unnamed: L2.2, Q2.3, R9.2, U3.3
unnamed: R10.1, SJ1.2, U3.15
unnamed: C10.1, R6.2, U3.7
unnamed: C10.2, R7.2, U3.8
unnamed: Q3.1, U5.2
unnamed: R13.2, R14.1, U5.4
unnamed: C19.2, U5.6
unnamed: L3.2, Q3.3, R14.2, U5.3
unnamed: R15.1, SJ3.2, U5.15
unnamed: C17.1, R11.2, U5.7
unnamed: C17.2, R12.2, U5.8
unnamed: Q4.1, U8.2
unnamed: R18.2, R19.1, U8.4
unnamed: C26.2, U8.6
unnamed: L4.2, Q4.3, R19.2, U8.3
unnamed: R20.1, SJ4.2, U8.15
unnamed: C24.1, R16.2, U8.7
unnamed: C24.2, R17.2, U8.8
unnamed: Q5.1, U10.2
unnamed: R23.2, R24.1, U10.4
unnamed: C33.2, U10.6
unnamed: L5.2, Q5.3, R24.2, U10.3
unnamed: R25.1, SJ5.2, U10.15
unnamed: C31.1, R21.2, U10.7
unnamed: C31.2, R22.2, U10.8
unnamed: Q6.1, U12.2
unnamed: R28.2, R29.1, U12.4
unnamed: C40.2, U12.6
unnamed: L6.2, Q6.3, R29.2, U12.3
unnamed: R30.1, SJ6.2, U12.15
unnamed: C38.1, R26.2, U12.7
unnamed: C38.2, R27.2, U12.8
unnamed: Q7.1, U14.2
unnamed: R33.2, R34.1, U14.4
unnamed: C47.2, U14.6
unnamed: L7.2, Q7.3, R34.2, U14.3
unnamed: R35.1, SJ7.2, U14.15
unnamed: C45.1, R31.2, U14.7
unnamed: C45.2, R32.2, U14.8
unnamed: Q8.1, U16.2
unnamed: R38.2, R39.1, U16.4
unnamed: C54.2, U16.6
unnamed: L8.2, Q8.3, R39.2, U16.3
unnamed: R40.1, SJ8.2, U16.15
unnamed: C52.1, R36.2, U16.7
unnamed: C52.2, R37.2, U16.8
unnamed: Q9.1, U18.2
unnamed: R43.2, R44.1, U18.4
unnamed: C61.2, U18.6
unnamed: L9.2, Q9.3, R44.2, U18.3
unnamed: R45.1, SJ9.2, U18.15
unnamed: C59.1, R41.2, U18.7
unnamed: C59.2, R42.2, U18.8
unnamed: Q10.1, U20.2
unnamed: R48.2, R49.1, U20.4
unnamed: C68.2, U20.6
unnamed: L10.2, Q10.3, R49.2, U20.3
unnamed: R50.1, SJ10.2, U20.15
unnamed: C66.1, R46.2, U20.7
unnamed: C66.2, R47.2, U20.8
unnamed: Q11.1, U22.2
unnamed: R53.2, R54.1, U22.4
unnamed: C75.2, U22.6
unnamed: L11.2, Q11.3, R54.2, U22.3
unnamed: R55.1, SJ11.2, U22.15
unnamed: C73.1, R51.2, U22.7
unnamed: C73.2, R52.2, U22.8
unnamed: Q12.1, U24.2
unnamed: R58.2, R59.1, U24.4
unnamed: C82.2, U24.6
unnamed: L12.2, Q12.3, R59.2, U24.3
unnamed: R60.1, SJ12.2, U24.15
unnamed: C80.1, R56.2, U24.7
unnamed: C80.2, R57.2, U24.8
unnamed: Q13.1, U26.2
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

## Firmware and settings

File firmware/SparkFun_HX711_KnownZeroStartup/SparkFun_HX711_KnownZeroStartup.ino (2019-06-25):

/*
 Example using the SparkFun HX711 breakout board with a scale
 By: Nathan Seidle
 SparkFun Electronics
 Date: November 19th, 2014
 License: This code is public domain but you buy me a beer if you use this and we meet someday (Beerware license).
 
 Most scales require that there be no weight on the scale during power on. This sketch shows how to pre-load tare values
 so that you don't have to clear the scale between power cycles. This is good if you have something on the scale 
 all the time and need to reset the Arduino and not need to tare the scale.
 
 This example code uses bogde's excellent library: https://github.com/bogde/HX711
 bogde's library is released under a GNU GENERAL PUBLIC LICENSE
 
 The HX711 does one thing well: read load cells. The breakout board is compatible with any wheat-stone bridge
 based load cell which should allow a user to measure everything from a few grams to tens of tons.

 Arduino pin 2 -> HX711 CLK
 3 -> DOUT
 5V -> VCC
 GND -> GND
 
 The HX711 board can be powered from 2.7V to 5V so the Arduino 5V power should be fine.
 
*/

#include "HX711.h" //This library can be obtained here http://librarymanager/All#Avia_HX711

#define calibration_factor -7050.0 //This value is obtained using the SparkFun_HX711_Calibration sketch
#define zero_factor 8421804 //This large value is obtained using the SparkFun_HX711_Calibration sketch

#define LOADCELL_DOUT_PIN  3
#define LOADCELL_SCK_PIN  2

HX711 scale;

void setup() {
  Serial.begin(9600);
  Serial.println("Demo of zeroing out a scale from a known value");

  scale.begin(LOADCELL_DOUT_PIN, LOADCELL_SCK_PIN);
  scale.set_scale(calibration_factor); //This value is obtained by using the SparkFun_HX711_Calibration sketch
  scale.set_offset(zero_factor); //Zero out the scale using a previously known zero_factor

  Serial.println("Readings:");
}

void loop() {
  Serial.print("Reading: ");
  Serial.print(scale.get_units(), 1); //scale.get_units() returns a float
  Serial.print(" lbs"); //You can change to kg but you'll need to change the calibration_factor
  Serial.println();
}

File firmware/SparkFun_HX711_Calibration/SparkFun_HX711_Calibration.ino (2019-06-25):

/*
 Example using the SparkFun HX711 breakout board with a scale
 By: Nathan Seidle
 SparkFun Electronics
 Date: November 19th, 2014
 License: This code is public domain but you buy me a beer if you use this and we meet someday (Beerware license).
 
 This is the calibration sketch. Use it to determine the calibration_factor that the main example uses. It also
 outputs the zero_factor useful for projects that have a permanent mass on the scale in between power cycles.
 
 Setup your scale and start the sketch WITHOUT a weight on the scale
 Once readings are displayed place the weight on the scale
 Press +/- or a/z to adjust the calibration_factor until the output readings match the known weight
 Use this calibration_factor on the example sketch
 
 This example assumes pounds (lbs). If you prefer kilograms, change the Serial.print(" lbs"); line to kg. The
 calibration factor will be significantly different but it will be linearly related to lbs (1 lbs = 0.453592 kg).
 
 Your calibration factor may be very positive or very negative. It all depends on the setup of your scale system
 and the direction the sensors deflect from zero state

 This example code uses bogde's excellent library: https://github.com/bogde/HX711
 bogde's library is released under a GNU GENERAL PUBLIC LICENSE

 Arduino pin 2 -> HX711 CLK
 3 -> DOUT
 5V -> VCC
 GND -> GND
 
 Most any pin on the Arduino Uno will be compatible with DOUT/CLK.
 
 The HX711 board can be powered from 2.7V to 5V so the Arduino 5V power should be fine.
 
*/

#include "HX711.h" //This library can be obtained here http://librarymanager/All#Avia_HX711

#define LOADCELL_DOUT_PIN  3
#define LOADCELL_SCK_PIN  2

HX711 scale;

float calibration_factor = -7050; //-7050 worked for my 440lb max scale setup

void setup() {
  Serial.begin(9600);
  Serial.println("HX711 calibration sketch");
  Serial.println("Remove all weight from scale");
  Serial.println("After readings begin, place known weight on scale");
  Serial.println("Press + or a to increase calibration factor");
  Serial.println("Press - or z to decrease calibration factor");

  scale.begin(LOADCELL_DOUT_PIN, LOADCELL_SCK_PIN);
  scale.set_scale();
  scale.tare();	//Reset the scale to 0

  long zero_factor = scale.read_average(); //Get a baseline reading
  Serial.print("Zero factor: "); //This can be used to remove the need to tare the scale. Useful in permanent scale projects.
  Serial.println(zero_factor);
}

void loop() {

  scale.set_scale(calibration_factor); //Adjust to this calibration factor

  Serial.print("Reading: ");
  Serial.print(scale.get_units(), 1);
  Serial.print(" lbs"); //Change this to kg and re-adjust the calibration factor if you follow SI units like a sane person
  Serial.print(" calibration_factor: ");
  Serial.print(calibration_factor);
  Serial.println();

  if(Serial.available())
  {
    char temp = Serial.read();
    if(temp == '+' || temp == 'a')
      calibration_factor += 10;
    else if(temp == '-' || temp == 'z')
      calibration_factor -= 10;
  }
}

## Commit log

2014-11-17 Hardware is ready for protos.
    Passed the QC checklist.
    [SparkFun HX711 Load Cell.brd, SparkFun HX711 Load Cell.sch]
2014-11-19 Changes from initial QC checklist. Adding datasheet.
    [SparkFun HX711 Load Cell.brd, SparkFun HX711 Load Cell.sch]
2014-11-24 Spread out 0603 components and fixed silk. See issue 1.
    [SparkFun HX711 Load Cell.brd, SparkFun HX711 Load Cell.sch]
2014-11-26 Broke out channel B. Adjusted some traces.
    [SparkFun HX711 Load Cell.brd, SparkFun HX711 Load Cell.sch]
2014-11-26 Fix issue #3. Straightened traces out of SMD pads.
    [SparkFun HX711 Load Cell.brd]
2014-12-04 Silk label adjustment. Added cnt for shielding (yellow).
    Some load cells have a 5th wire that is yellow that shields the four
    wires. Added a ground connection for this 5th wire.
    [SparkFun HX711 Load Cell.brd, SparkFun HX711 Load Cell.sch]
2014-12-07 Change AVDD resistors to output closer to 5V
    [SparkFun HX711 Load Cell.brd, SparkFun HX711 Load Cell.sch]
2015-01-19 Fixing issues #6.
    [SparkFun HX711 Load Cell.brd, SparkFun HX711 Load Cell.sch]
2015-01-26 Fixed feedback from eng review.
    Moved VCC trace out of tKeepout. Fixed 4-way junction on schematic.
    Moved schematic part for standoff holes to proper location.
    [SparkFun HX711 Load Cell.brd, SparkFun HX711 Load Cell.sch]
2015-01-30 Moving all headers onto horizontal grid.
    [SparkFun HX711 Load Cell.brd]
2015-01-30 Extraneous layers removed.
    [SparkFun HX711 Load Cell.brd]
2015-03-03 v10 panel created
    [SparkFun_HX711_Load_Cell_Panel_v10.brd]
2016-03-22 Revision 11 changes
    -Added 3.3uH inductor, this should allow for greater resolution in the
    HX711 ADC.
    -Separated analog and digital supply voltage, which allows 3.3V uCs to
    communicate without additional hardware.
    -Added 0.1uF cap to digital supply.
    [SparkFun HX711 Load Cell.brd, SparkFun HX711 Load Cell.sch]
2016-03-29 Revision 11 (Update)
    Corrected net label from N$5 to AVDD.
    [SparkFun HX711 Load Cell.brd, SparkFun HX711 Load Cell.sch]
2016-05-09 Rotated copper for version number
    Now matches with board silk
    [SparkFun HX711 Load Cell.brd]
2016-05-10 deleted old panel
    [SparkFun_HX711_Load_Cell_Panel_v10.brd]
2016-05-10 V11 Update
    Removed spaces from file names
    Fixed silk causing CAM errors
    [SparkFun_HX711_Load_Cell.brd, SparkFun_HX711_Load_Cell.sch]
2016-05-10 created panel v11
    [SparkFun_HX711_Load_Cell-Panel-v11.brd]
2019-05-15 Updated Schematic and Datasheet
    -Updated to the newest datasheet for the HX711 which corrected the equation from AVDD = VBG(R1+R2)/R1 to AVDD = VBG(R1+R2)/R2.
    -Updated the schematic with the correct equation
    [SparkFun_HX711_Load_Cell.sch]
2019-06-25 Fix examples to match rev on HX711 library
    [SparkFun_HX711_Calibration.ino, SparkFun_HX711_Example.ino, SparkFun_HX711_KnownZeroStartup.ino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]

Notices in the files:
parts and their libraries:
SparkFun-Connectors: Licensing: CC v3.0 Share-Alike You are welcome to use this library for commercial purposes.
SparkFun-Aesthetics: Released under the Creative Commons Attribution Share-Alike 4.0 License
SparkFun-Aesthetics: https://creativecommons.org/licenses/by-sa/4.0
